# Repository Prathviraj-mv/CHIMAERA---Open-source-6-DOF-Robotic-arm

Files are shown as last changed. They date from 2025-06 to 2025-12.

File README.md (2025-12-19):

# CHIMAERA---Open-source-5-DOF-Robotic-arm

Multi-joint articulated manipulator designed for precision movement and small-scale automation, experimentation, and learning advanced control.
<p>
  
</p>

# Degrees of Freedom (DOF): 5 DOF 

Segments:

Base Rotation: Provides 360° rotation using a NEMA 17 stepper or high-torque servo.

Shoulder Joint: Actuated using a NEMA 17 stepper with a 5:1 gear reduction, allowing smooth lifting and positioning.

Elbow Joint: Controlled by an NEMA 17, providing stable controlled movement within a physical range of -30° to +60° from horizontal.

Wrist Joint: MG996R servo, and NEMA 17 capable of up to 360° rotation or constrained movement for orientation control.

Gripper: MG996R Servo-powered for object holding.

<p>
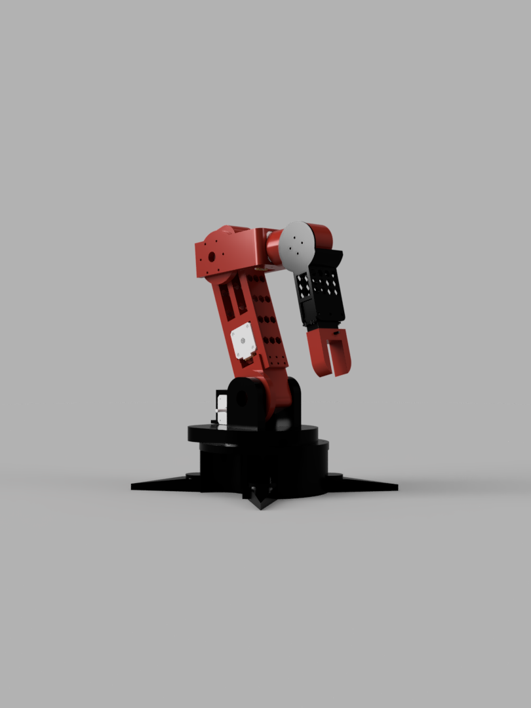
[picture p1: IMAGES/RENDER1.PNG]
  
</p>

# Components:
| **Category** | **Component** |
| --- | --- |
| **Structure** | PLA linkages | 
| **Actuators** | **Base rotation:** NEMA 17 stepper | 
| | **Shoulder joint:** NEMA 17 stepper | 
| | **Elbow joint:** NEMA 17 stepper | 
| | **Wrist pitch:** MG995S | 
| | **Gripper:**  MG995S | 
| | **Wrist rotation:** NEMA 17 stepper 
| **Sensors** | AS5600 magnetic encoder | 
| **Electronics** | Arduino Mega | 
| | RAMPS + Stepper motor driver (A4988) | 
| | Buck converter (12V → 7V/6V) | 
| **Power Supply** | LiPo battery (3S) |

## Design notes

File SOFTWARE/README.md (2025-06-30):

python software incoming for inverse kinematics visualization

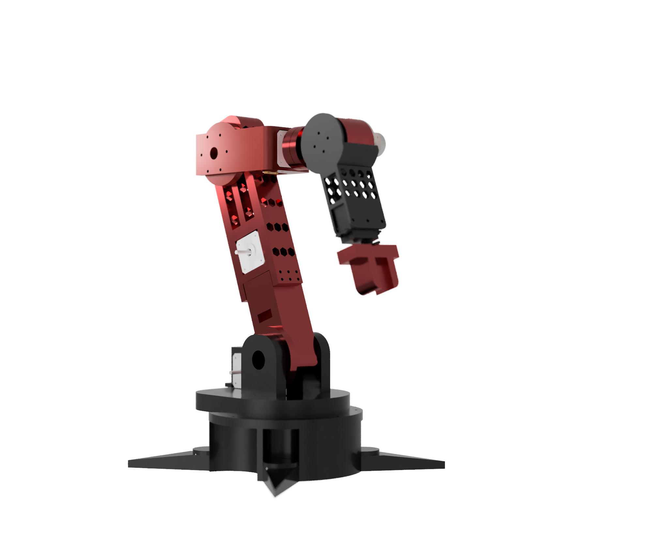
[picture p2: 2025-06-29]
IMAGES/wrist_2025-Jun-29_02-11-46PM-000_CustomizedView11417113252.jpg

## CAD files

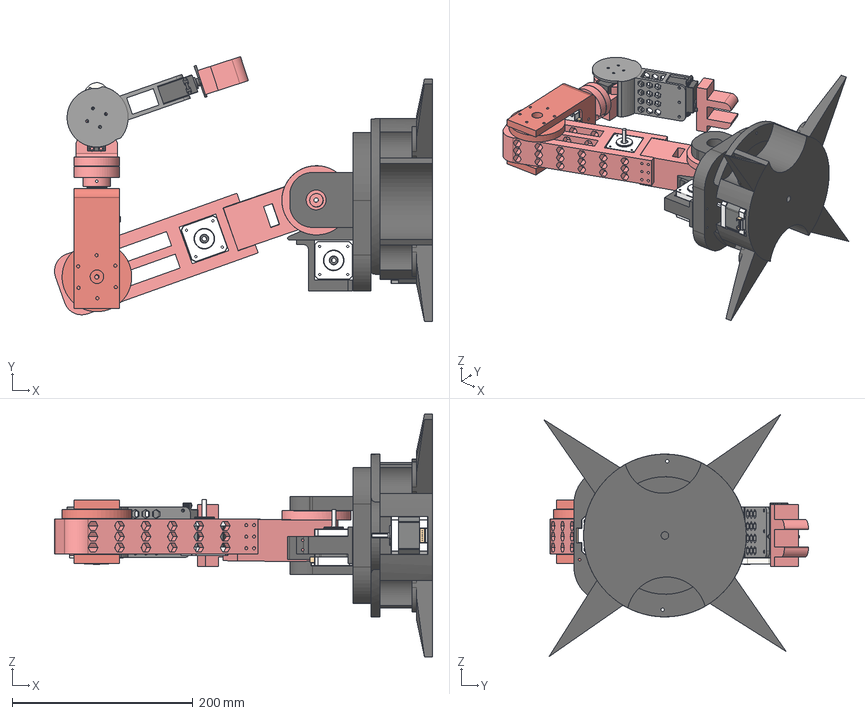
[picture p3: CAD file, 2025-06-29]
CAD/combined.step
417.8 x 292.7 x 268.2 mm
Connector x 2
Servo Body x 2
Rubber Feet x 2
Nima 17 40x42x5mm x 5
base1
slipring

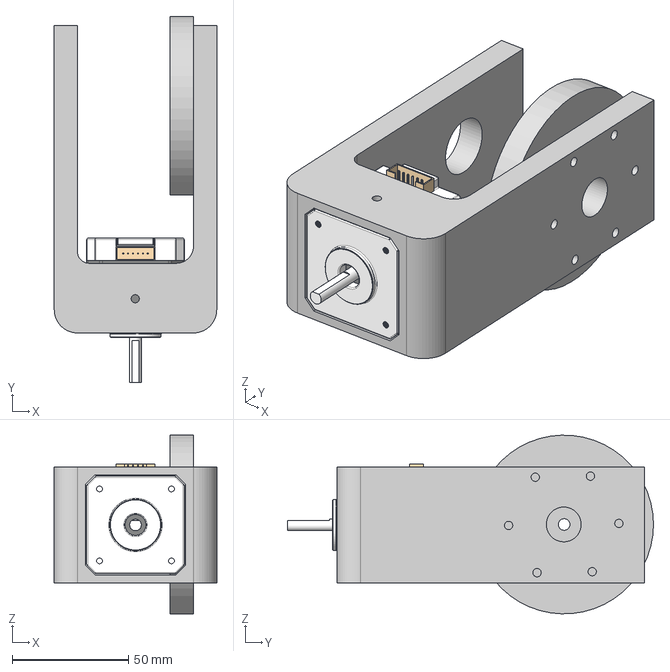
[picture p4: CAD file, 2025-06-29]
CAD/elbow.step
70.0 x 157.7 x 77.0 mm

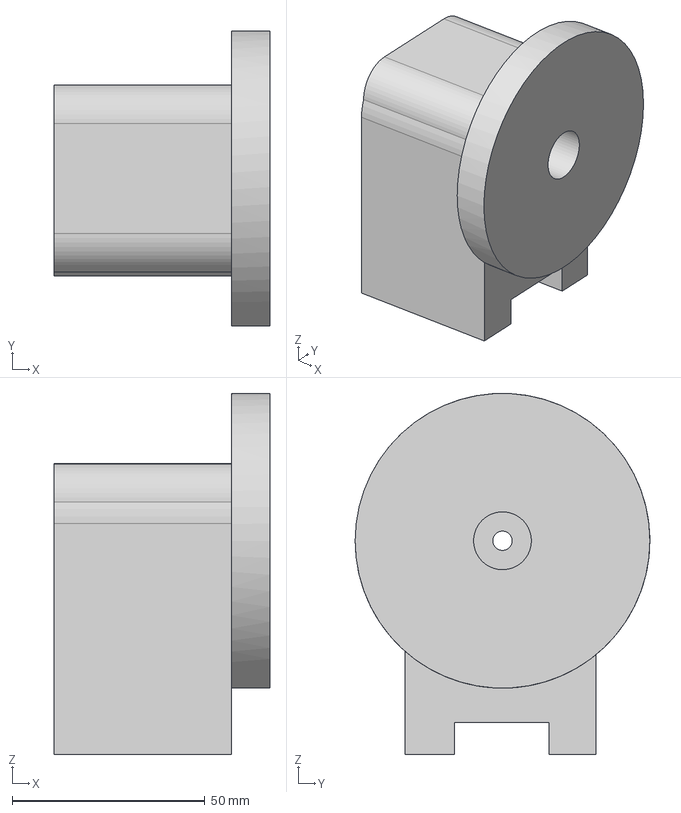
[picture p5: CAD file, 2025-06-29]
CAD/shoulder1.step
56.0 x 76.5 x 93.7 mm

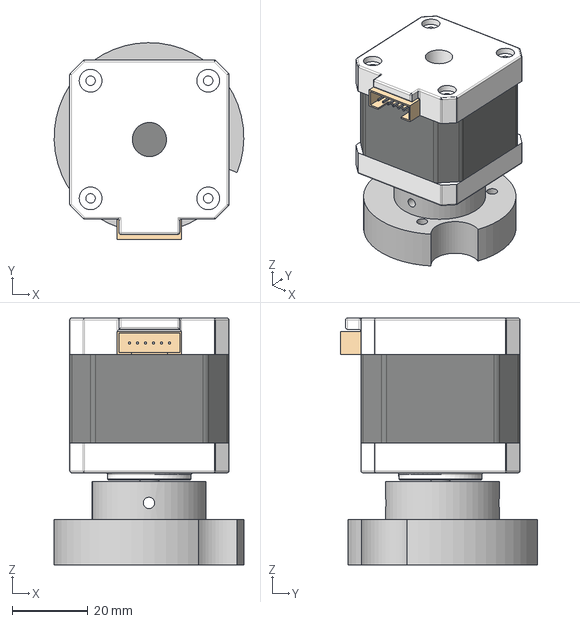
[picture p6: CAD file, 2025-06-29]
CAD/wrist coupler.step
50.0 x 51.8 x 65.1 mm

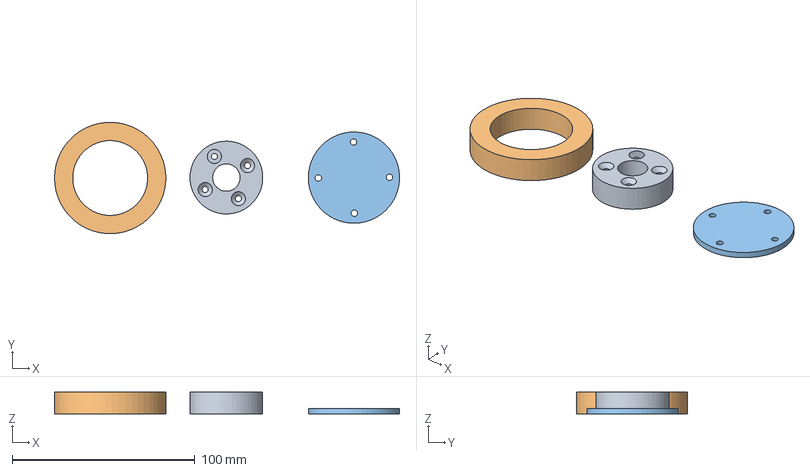
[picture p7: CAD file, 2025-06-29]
CAD/disc.step
189.0 x 61.0 x 12.0 mm

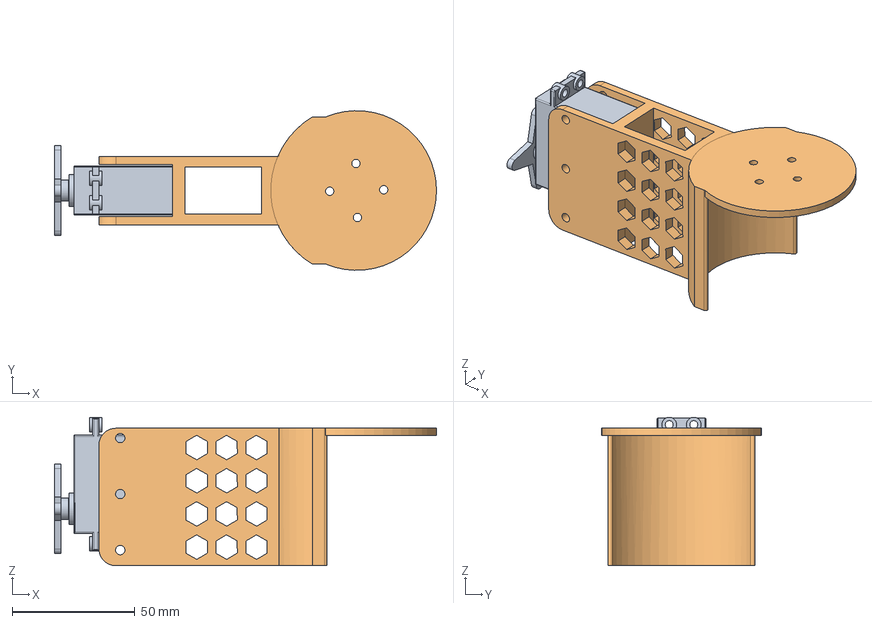
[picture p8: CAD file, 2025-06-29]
CAD/wrist.step
155.6 x 65.0 x 60.5 mm
Connector
Servo Body
Rubber Feet

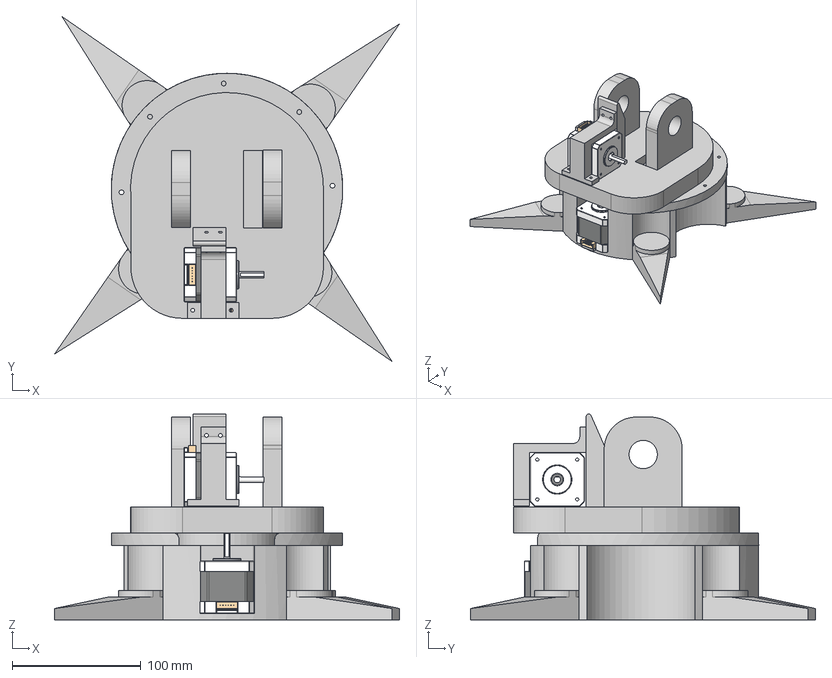
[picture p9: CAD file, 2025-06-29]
CAD/base.step
268.2 x 268.2 x 160.1 mm
Nima 17 40x42x5mm x 2
slipring

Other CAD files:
CAD/GT2_Pulley_120T_5_R.step

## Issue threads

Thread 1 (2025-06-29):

Rename "Software" to "Firmware" for Microcontroller Code

svenar-nl, 2025-06-29:
I recommend renaming all code that runs on the microcontroller of the robot arm to "Firmware" and reserving the term "Software" for any programs that run on a PC, phone, or other external devices used to control the robot arm.

The distinction between firmware and software helps clarify where the code runs.

This naming convention aligns with common industry terminology, improving readability and maintainability for future contributors.

Prathviraj-mv, 2025-06-30:
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

Alright ill do that, thanks for the insight

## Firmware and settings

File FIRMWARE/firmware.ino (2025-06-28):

#include <AccelStepper.h>

// === CONFIGURATION ===
#define L1 23.0
#define L2 17.5

#define DRIVER 1

// SHOULDER
#define SHOULDER_STEP_PIN 54
#define SHOULDER_DIR_PIN  55
#define SHOULDER_ENABLE_PIN 38

// ELBOW
#define ELBOW_STEP_PIN 60
#define ELBOW_DIR_PIN  61
#define ELBOW_ENABLE_PIN 56

// BASE
#define BASE_STEP_PIN 46
#define BASE_DIR_PIN  48
#define BASE_ENABLE_PIN 62

#define STEPS_PER_REV 200
#define MICROSTEPPING 8
#define GEAR_RATIO 5.0

#define MAX_SPEED 1600
#define ACCELERATION 800

// === JOINT CONSTRAINTS ===
float SHOULDER_MIN_ANGLE = 75.0;
float SHOULDER_MAX_ANGLE = 135.0;
float ELBOW_MIN_ANGLE = 0.0;
float ELBOW_MAX_ANGLE = 75.0;
float BASE_MIN_ANGLE = 0.0;
float BASE_MAX_ANGLE = 180.0;

// === STATE ===
AccelStepper stepperShoulder(DRIVER, SHOULDER_STEP_PIN, SHOULDER_DIR_PIN);
AccelStepper stepperElbow(DRIVER, ELBOW_STEP_PIN, ELBOW_DIR_PIN);
AccelStepper stepperBase(DRIVER, BASE_STEP_PIN, BASE_DIR_PIN);

float shoulderAngleCurrent = 135.0; // mechanical reference (up)
float elbowAngleCurrent = 0.0;      // straight
float baseAngleCurrent = 90.0;      // center

// === FUNCTIONS ===
long angleToStepsAbs(float angle_deg) {
    float stepsPerMotorRev = STEPS_PER_REV * MICROSTEPPING;
    float stepsPerDegree = stepsPerMotorRev / 360.0;
    float requiredMotorAngle = angle_deg * GEAR_RATIO;
    return requiredMotorAngle * stepsPerDegree;
}

void moveToAngles(float theta1_deg, float theta2_deg, float base_deg, bool baseUpdate) {
    // Clip angles safely
    theta1_deg = constrain(theta1_deg, SHOULDER_MIN_ANGLE, SHOULDER_MAX_ANGLE);
    theta2_deg = constrain(theta2_deg, ELBOW_MIN_ANGLE, ELBOW_MAX_ANGLE);
    if (baseUpdate) {
        base_deg = constrain(base_deg, BASE_MIN_ANGLE, BASE_MAX_ANGLE);
        stepperBase.moveTo(angleToStepsAbs(base_deg));
        baseAngleCurrent = base_deg;
    }

    stepperShoulder.moveTo(angleToStepsAbs(theta1_deg));
    stepperElbow.moveTo(angleToStepsAbs(theta2_deg));

    shoulderAngleCurrent = theta1_deg;
    elbowAngleCurrent = theta2_deg;

    Serial.print("Moving -> Shoulder: "); Serial.print(theta1_deg);
    Serial.print(" deg, Elbow: "); Serial.print(theta2_deg);
    Serial.print(" deg, Base: "); Serial.println(baseAngleCurrent);
}

void computeIKAndMove(float x, float y, float theta_base) {
    float D = (x * x + y * y - L1 * L1 - L2 * L2) / (2 * L1 * L2);
    D = constrain(D, -1.0, 1.0);

    float theta2_rad = atan2(sqrt(1 - D * D), D);
    float theta1_rad = atan2(y, x) - atan2(L2 * sin(theta2_rad), L1 + L2 * cos(theta2_rad));

    float theta2_deg = theta2_rad * 180.0 / PI;
    float theta1_deg_geom = theta1_rad * 180.0 / PI;

    // Adjust for your mechanical convention:
    float theta1_deg_mech = 135.0 - theta1_deg_geom; // 0 geom = 135 mech (up)
    float theta2_deg_mech = theta2_deg;              // direct

    // Use current base if theta_base == 0
    bool baseUpdate = false;
    float base_deg = baseAngleCurrent;
    if (theta_base != 0.0) {
        base_deg = theta_base;
        baseUpdate = true;
    }

    moveToAngles(theta1_deg_mech, theta2_deg_mech, base_deg, baseUpdate);
}

void homeArm() {
    Serial.println("Homing all joints.");
    moveToAngles(135.0, 0.0, 90.0, true);
}

void setup() {
    Serial.begin(9600);

    pinMode(SHOULDER_ENABLE_PIN, OUTPUT);
    pinMode(ELBOW_ENABLE_PIN, OUTPUT);
    pinMode(BASE_ENABLE_PIN, OUTPUT);

    digitalWrite(SHOULDER_ENABLE_PIN, LOW);
    digitalWrite(ELBOW_ENABLE_PIN, LOW);
    digitalWrite(BASE_ENABLE_PIN, LOW);

    stepperShoulder.setMaxSpeed(MAX_SPEED);
    stepperShoulder.setAcceleration(ACCELERATION);
    stepperElbow.setMaxSpeed(MAX_SPEED);
    stepperElbow.setAcceleration(ACCELERATION);
    stepperBase.setMaxSpeed(MAX_SPEED);
    stepperBase.setAcceleration(ACCELERATION);

    // Set initial positions:
    stepperShoulder.setCurrentPosition(angleToStepsAbs(shoulderAngleCurrent));
    stepperElbow.setCurrentPosition(angleToStepsAbs(elbowAngleCurrent));
    stepperBase.setCurrentPosition(angleToStepsAbs(baseAngleCurrent));

    Serial.println("3-DOF IK Arm Ready. Send: x y theta or h: to home.");
}

void loop() {
    if (Serial.available()) {
        String input = Serial.readStringUntil('\n');
        input.trim();

        if (input.startsWith("h:")) {
            homeArm();
        } else {
            int firstSpace = input.indexOf(' ');
            int secondSpace = input.indexOf(' ', firstSpace + 1);

            if (firstSpace > 0 && secondSpace > firstSpace) {
                float x = input.substring(0, firstSpace).toFloat();
                float y = input.substring(firstSpace + 1, secondSpace).toFloat()+ 10;
                float theta = input.substring(secondSpace + 1).toFloat();
                computeIKAndMove(x, y, theta);
            } else {
                Serial.println("❌ Invalid input. Use: x y theta");
            }
        }
    }

    stepperShoulder.run();
    stepperElbow.run();
    stepperBase.run();
}

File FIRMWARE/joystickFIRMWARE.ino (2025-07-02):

#include <AccelStepper.h>
#include <Servo.h>

#define DRIVER 1

// RAMPS 1.4 Pins
#define X_STEP_PIN    54
#define X_DIR_PIN     55
#define X_ENABLE_PIN  38

#define Y_STEP_PIN    60
#define Y_DIR_PIN     61
#define Y_ENABLE_PIN  56

#define Z_STEP_PIN    46
#define Z_DIR_PIN     48
#define Z_ENABLE_PIN  62

#define A_STEP_PIN    36   // New stepper
#define A_DIR_PIN     34
#define A_ENABLE_PIN  30

#define SERVO1_PIN    11
#define SERVO2_PIN    5    // New servo

#define MAX_SPEED     1600
#define ACCELERATION  800

// Create steppers
AccelStepper stepperX(DRIVER, X_STEP_PIN, X_DIR_PIN); // Elbow
AccelStepper stepperY(DRIVER, Y_STEP_PIN, Y_DIR_PIN); // Shoulder
AccelStepper stepperZ(DRIVER, Z_STEP_PIN, Z_DIR_PIN); // Base
AccelStepper stepperA(DRIVER, A_STEP_PIN, A_DIR_PIN); // New stepper

// Create servos
Servo servo1; // Wrist servo
Servo servo2; // New servo

// Conversion
float degToSteps = 10.0; // Adjust as needed

// Target angles
float targetElbowDeg = 0;
float targetShoulderDeg = 0;
float targetBaseDeg = 0;
float targetAStepperDeg = 0; // New stepper
int targetWristDeg = 90;
int targetServo2Deg = 90;    // New servo

void setup() {
  Serial.begin(9600);

  // Enable drivers
  pinMode(X_ENABLE_PIN, OUTPUT);
  pinMode(Y_ENABLE_PIN, OUTPUT);
  pinMode(Z_ENABLE_PIN, OUTPUT);
  pinMode(A_ENABLE_PIN, OUTPUT);

  digitalWrite(X_ENABLE_PIN, LOW);
  digitalWrite(Y_ENABLE_PIN, LOW);
  digitalWrite(Z_ENABLE_PIN, LOW);
  digitalWrite(A_ENABLE_PIN, LOW);

  // Stepper setup
  stepperX.setMaxSpeed(MAX_SPEED);
  stepperX.setAcceleration(ACCELERATION);

  stepperY.setMaxSpeed(MAX_SPEED);
  stepperY.setAcceleration(ACCELERATION);

  stepperZ.setMaxSpeed(MAX_SPEED);
  stepperZ.setAcceleration(ACCELERATION);

  stepperA.setMaxSpeed(MAX_SPEED);
  stepperA.setAcceleration(ACCELERATION);

  // Servo setup
  servo1.attach(SERVO1_PIN);
  servo2.attach(SERVO2_PIN);

  servo1.write(targetWristDeg);
  servo2.write(targetServo2Deg);

  Serial.println("Ready: Send x(shoulder), y(elbow), v(base), a(stepper4), z(wrist), c(servo2), h(home).");
}

void loop() {
  if (Serial.available()) {
    String cmd = Serial.readStringUntil('\n');
    cmd.trim();
    cmd.toLowerCase();

    if (cmd.length() == 1 && cmd.charAt(0) == 'h') {
      // Home all
      targetElbowDeg = 0;
      targetShoulderDeg = 0;
      targetBaseDeg = 0;
      targetAStepperDeg = 0;
      targetWristDeg = 90;
      targetServo2Deg = 90;

      stepperX.moveTo(targetElbowDeg * degToSteps);
      stepperY.moveTo((-targetShoulderDeg) * degToSteps);
      stepperZ.moveTo(targetBaseDeg * degToSteps);
      stepperA.moveTo(targetAStepperDeg * degToSteps);

      servo1.write(targetWristDeg);
      servo2.write(targetServo2Deg);

      Serial.println("Homing all axes and servos.");
    }

    else if (cmd.length() > 1) {
      char c = cmd.charAt(0);
      float angle = cmd.substring(1).toFloat();

      switch (c) {
        case 'y': // Elbow
          targetElbowDeg = angle;
          stepperX.moveTo(-targetElbowDeg * degToSteps);
          Serial.print("Elbow target angle: "); Serial.println(targetElbowDeg);
          break;

        case 'v': // Base
          targetBaseDeg = angle;
          stepperZ.moveTo(targetBaseDeg * degToSteps);
          Serial.print("Base target angle: "); Serial.println(targetBaseDeg);
          break;

        case 'x': // Shoulder
          targetShoulderDeg = angle;
          stepperY.moveTo(targetShoulderDeg * degToSteps);
          Serial.print("Shoulder target angle: "); Serial.println(targetShoulderDeg);
          break;

        case 'a': // New stepper
          targetAStepperDeg = angle;
          stepperA.moveTo(targetAStepperDeg * degToSteps);
          Serial.print("Stepper A target angle: "); Serial.println(targetAStepperDeg);
          break;

        case 'z': // Wrist servo
          targetWristDeg = constrain(angle, 0, 180);
          servo1.write(targetWristDeg);
          Serial.print("Wrist servo angle: "); Serial.println(targetWristDeg);
          break;

        case 'c': // New servo
          targetServo2Deg = constrain(angle, 0, 180);
          servo2.write(targetServo2Deg);
          Serial.print("Servo2 angle: "); Serial.println(targetServo2Deg);
          break;

        default:
          Serial.println("Unknown command. Use x, y, v, a, z, c, or h.");
          break;
      }
    }
  }

  // Non-blocking stepper updates
  stepperX.run();
  stepperY.run();
  stepperZ.run();
  stepperA.run();
}

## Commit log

2025-06-22 Rename wrist v33.step to ARM.step
    [ARM.step, wrist v33.step]
2025-06-22 Rename wrist v32.png to ARM.png
